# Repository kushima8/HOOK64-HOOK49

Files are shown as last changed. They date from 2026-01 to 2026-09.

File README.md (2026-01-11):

# HOOK64&HOOK49
Keyboard that hooks up to LCD tablets

G8mPXopa0AAUuzB

## HOOK64 Build Guide

[はんだ付け済み版 ビルドガイド（日本語）](HOOK64/Documents//buildguide_pre-soldered.md)

## HOOK49 Build Guide

[はんだ付け済み版 ビルドガイド（日本語）](HOOK49/Documents//buildguide_pre-soldered.md)
  
120px-Cc-by-nc-sa_icon svg

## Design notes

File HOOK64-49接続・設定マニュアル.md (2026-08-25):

# HOOK64/49 接続・設定マニュアル

ビルドガイドに、注意事項などを記載しております。  
本書をお読みになる前に、必ずそちらをご確認ください。  
なお、本書は HOOK49 の画像・画面をもとに説明しておりますが、HOOK64 も操作手順は同じですので、読み替えてご覧ください。　　

## 1. ブックエンドの取り付け（液タブに設置する場合）

本製品を液晶タブレット（液タブ）の上辺に設置する場合は、**本体背面にブックエンドを取り付けて**ご使用ください。  

**手順**

1. 液タブ上辺の形状に合わせて、ブックエンドを適切な角度に折り曲げます。  
2. マスキングテープなどでブックエンドを本体背面に**仮止め**し、液タブに設置して位置や角度を確認します。  
3. 問題がなければ本体を一度取り外し、仮止めのテープをはがしたうえで、**ダクトテープやガムテープ等でブックエンドを本体背面にしっかりと固定**してください。  
   - ※固定時は、可能な限りネジ部分を避けてください。  

> **参考動画**  
> 先代機「HOOK69」の紹介動画内に、ブックエンドの取り付けを実演しているパートがあります。
> 折り曲げ方や固定位置のイメージがつかみやすいので、あわせてご覧ください。  
> https://youtu.be/qUh0zuOqxo4?t=560 （9分20秒ごろ〜）  
>
> ※HOOK64/49 とは筐体サイズが異なりますが、取り付けの考え方は同じです。  

## 2. 接続方法

HOOK64/49は、PCやiPadなどの機器とUSB接続して使用します。  
本体側の端子は USB Type-C もしくは USB Micro‐B です。  

### ■ 使用するケーブル

- Type-C/Micro‐B ⇄ Type-A
- Type-C/Micro‐B ⇄ Type-C  
  ※必ず「データ通信対応ケーブル」をご使用ください。充電専用ケーブルでは動作しません。  

USB端子は精密部品です。  
ケーブルを横方向に強く引っ張ると破損の原因になります。  
必ずまっすぐ抜き差ししてください。  

## 3. 内部のマイコンについて

HOOK64/49の内部には、ピンク色もしくは青色の小さな基板が入っています。  
これがマイコンです。  
このマイコンがHOOK64/49全体の動作を制御しPCとの接続口となっており、取り外すことができます。  

内部のマイコン

※画像はオプションの液晶付きモデルです。液晶がない場合、マイコンはカバーで覆われています。  

これは、

- 故障時に交換しやすくするため
- USB端子に強い力がかかった際に、本体基板へのダメージを減らすため

の設計です。  

そのため、衝撃などで外れることがありますが、**故障ではありません。**  

カバーにより外れにくい構造になっていますが、万が一外れてしまった場合はご連絡ください。  

## 4. Remapとは？

Remapは、ブラウザ上でキーボードの設定を変更できるWebアプリです。  
ソフトのインストールは不要で、Chromeブラウザのみで使用できます。  

Remapでは以下の設定が可能です。  

- キー配置変更
- レイヤー設定
- ダイヤル操作設定

## 5. Remapの使い方

### ① サイトを開く

https://remap-keys.app/  

「Start Remap for your keyboard」をクリックします。  

### ② キーボードを選択

「+KEYBOARD」をクリックします。  

表示された一覧から **HOOK64/49** を選択してください。  

キーボードの選択

接続が成功すると、キーボードのレイアウト画面が表示されます。  

レイアウト画面

## 6. キーの動作確認

右上メニューから **テストマトリクスモード** を選択してください。  

テストマトリクスモードの選択

キーを押すと水色に変わります。  

すべてのキーが反応するか確認してください。  

マトリクステスト

※ダイヤルの回転部分は、このテストモードでは反応表示されません。正常な仕様です。  
ダイヤルの回転部分については、テキストエディターなどを使用して、割り当てた入力が実際に行われるか確認してください。  

各部の名称

## 7. キー配置、ダイヤル操作の変更方法

Remap画面で以下の設定が変更できます。  

- キーの役割
- ダイヤルの回転動作と押し込み

### ■ 基本は「ドラッグ＆ドロップ」で変更します

Remapでは、画面下部のキー一覧からドラッグ＆ドロップする方法が最も簡単です。  

**手順**

1. 画面下部に表示されているキー一覧から、設定したいキーを探します。  
2. マウスでそのキーをクリックしたまま、割り当てたいキーの位置までドラッグします。  
3. ドロップ（マウスを離す）すると設定が変更されます。  

直感的に操作できるため、基本的にはこの方法をおすすめします。  

### ■ キーをクリックして変更する方法

ドラッグ操作が難しい場合は、キーをクリックして直接変更することも可能です。  

1. 変更したいキーをクリックします。  
2. 表示されるキー一覧から割り当てたい機能を選択します。  

### ■ 設定を保存する（重要）

キーの設定を変更しただけでは、本体には保存されていません。  
必ず、右上の **「書き込み」ボタン** を押してください。  

設定変更後、右上の **書き込み** を押すと HOOK64/49に保存されます。  
保存しないと変更内容は反映されません。  

### ■ ダイヤル（回転）の設定方法

ダイヤル部分

ダイヤル部分には、  

- 左回転
- 右回転
- 押し込み

それぞれに別の機能を設定できます。  

ダイヤルの各動作をクリックし、機能を設定してください。  

設定後は必ず **書き込みボタン** を押してください。  

### ■ 文字キーを割り当てる場合

例：Aキーを割り当てたい場合  

- 対象キーをクリック
- 「Basic」カテゴリーから「A」を選択
- 設定後に **書き込み** を押す

### ■ ショートカット（同時押し）を割り当てる場合

例：Ctrl + Z を1キーで実行する場合  

1. 変更したいキーをクリック  

修飾キーの選択

2. Modifier（修飾キー）を選択  
3. Ctrlを選択  
4. Zキーを選択  

Ctrl + Z の設定  

5. 右上の **書き込み** を押す  

これで1キーで「Ctrl + Z」が実行されます。  

### ■ レイヤー機能について

HOOK64/49には **4つのレイヤー（0th〜3rd）** があります。  
レイヤーとは、キー配置を切り替える機能です。  

例：

- 0thレイヤー → 通常操作
- 1stレイヤー → ショートカット
- 2ndレイヤー → ブラシ操作
- 3rdレイヤー → アプリ専用

初期状態では、0thレイヤーがデフォルトのレイヤーになっています。  

現在どのレイヤーが有効かを確認したい場合は、Remapで同じ位置のキーに 0th〜3rdそれぞれ異なる文字を割り当ててください。  
そのキーを押したときに入力される文字で、現在のレイヤーを判別できます。  

### ■ レイヤー切替キーの設定

Remapで以下を割り当てます（Nはレイヤー番号）。

- **MO(N)** … 押している間だけNレイヤーになります
- **TG(N)** … 一度押すとNレイヤーに切り替わり、もう一度押すと元のレイヤーに戻ります
- **TO(N)** … 押すとNレイヤーに切り替わります
  もう一度押しても戻らないため、別のレイヤーに移る場合は他の `TO(N)` を押してください  

レイヤー設定後も、必ず **書き込み** を押してください。  

レイヤー切替キーは上記以外にもあります。  
詳しくはRemapおよびQMKの公式ドキュメントをご参照ください。

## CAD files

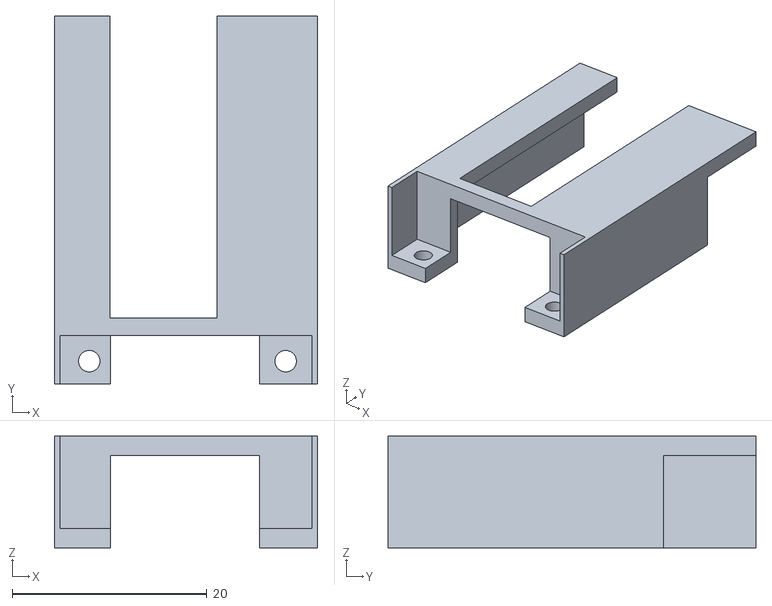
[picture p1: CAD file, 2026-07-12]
HOOK49/STL/hook49・64_cover_oled.stl
27.1 x 37.8 x 11.5

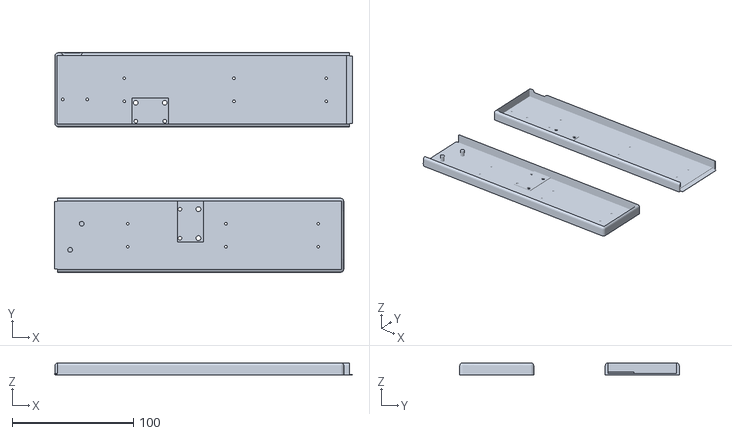
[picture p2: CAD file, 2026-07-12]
HOOK64/STL/hook64_case_V3.stl
245.8 x 181.1 x 10.3

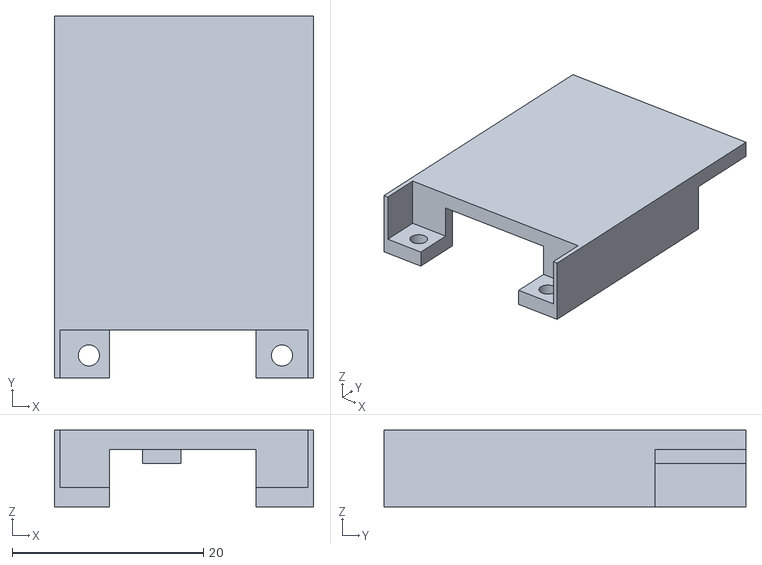
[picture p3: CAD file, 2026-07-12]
HOOK49/STL/hook49・64_cover_2.5.stl
27.1 x 37.8 x 8.00

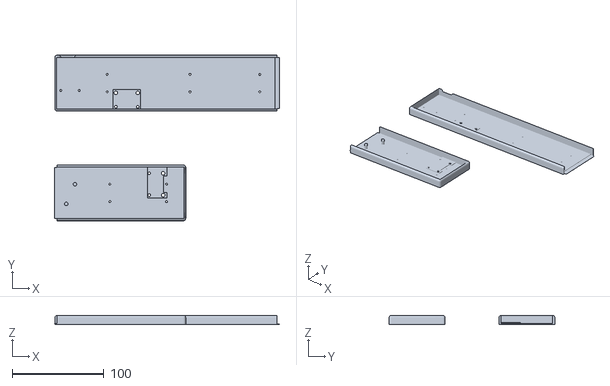
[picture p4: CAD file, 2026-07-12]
HOOK49/STL/hook49_case_V3.stl
245.8 x 181.1 x 10.3

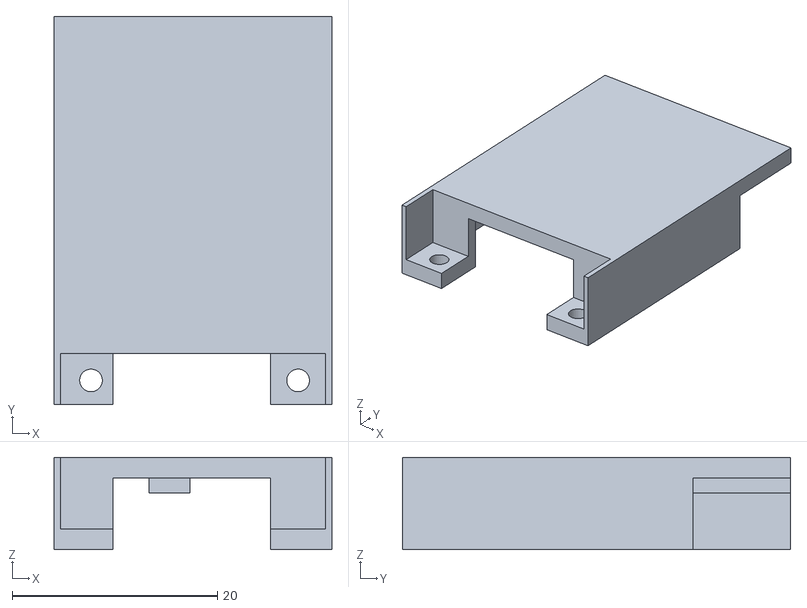
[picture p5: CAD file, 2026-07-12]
HOOK64/STL/hook49・64_cover_3.5.stl
27.1 x 37.8 x 9.00

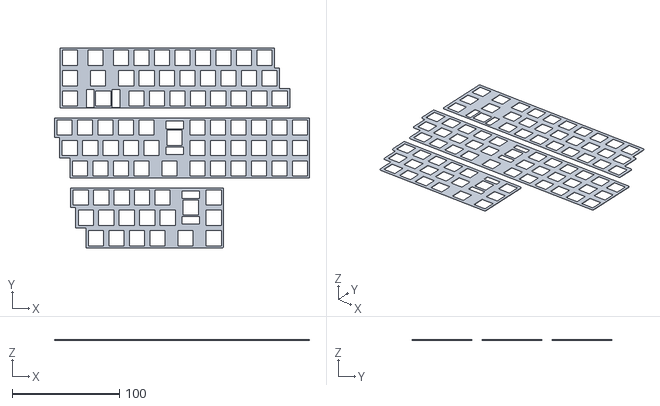
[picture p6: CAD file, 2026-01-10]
HOOK49/STL/hook49・64_plate.stl
237.5 x 186.0 x 1.20

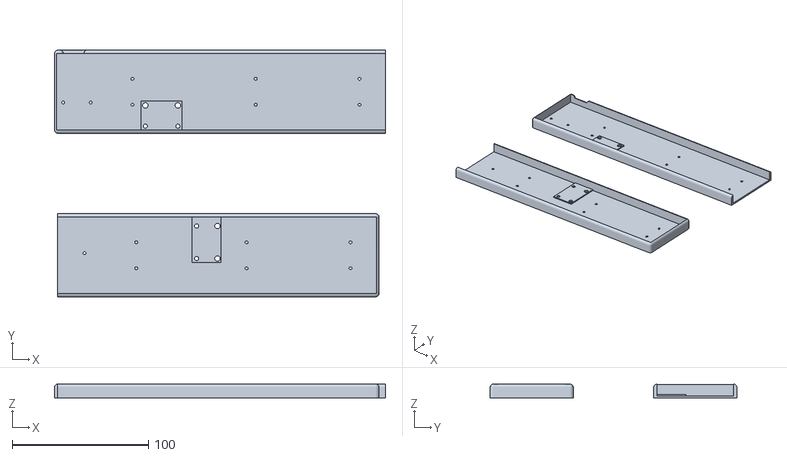
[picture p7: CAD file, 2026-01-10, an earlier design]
HOOK64/STL/hook64_case.stl
242.9 x 181.1 x 10.3

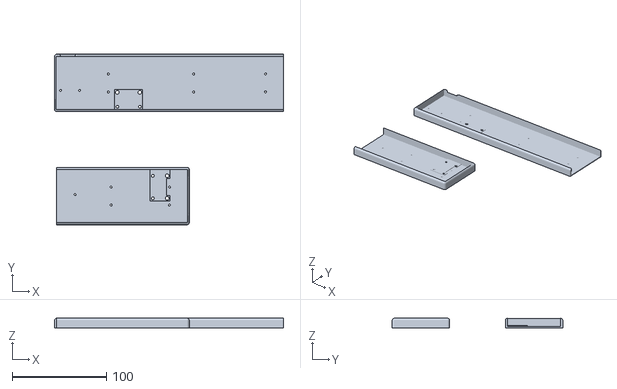
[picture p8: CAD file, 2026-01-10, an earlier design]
HOOK49/STL/hook49_case.stl
242.9 x 181.1 x 10.3

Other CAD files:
HOOK49/STL/hook49_case_V2.stl
HOOK64/STL/hook64_case_V2.stl

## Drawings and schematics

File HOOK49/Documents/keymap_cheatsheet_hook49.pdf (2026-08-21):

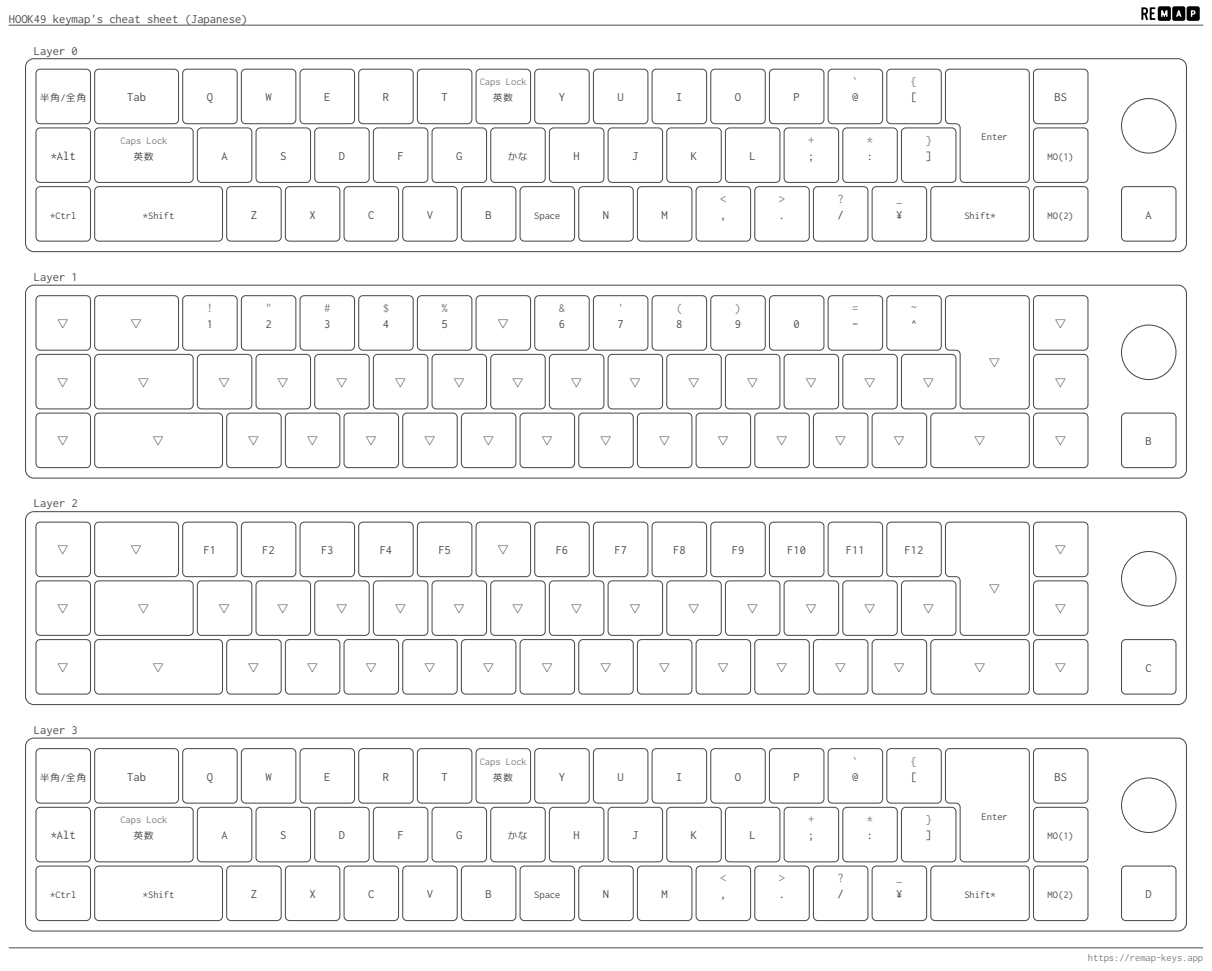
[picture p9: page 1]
Layer 0; Tab; Caps Lock; Enter; *Alt; *Ctrl; *Shift; Space; Shift*; Layer 1; Layer 2; Layer 3

HOOK49 keymap's cheat sheet (Japanese)

https://remap-keys.app

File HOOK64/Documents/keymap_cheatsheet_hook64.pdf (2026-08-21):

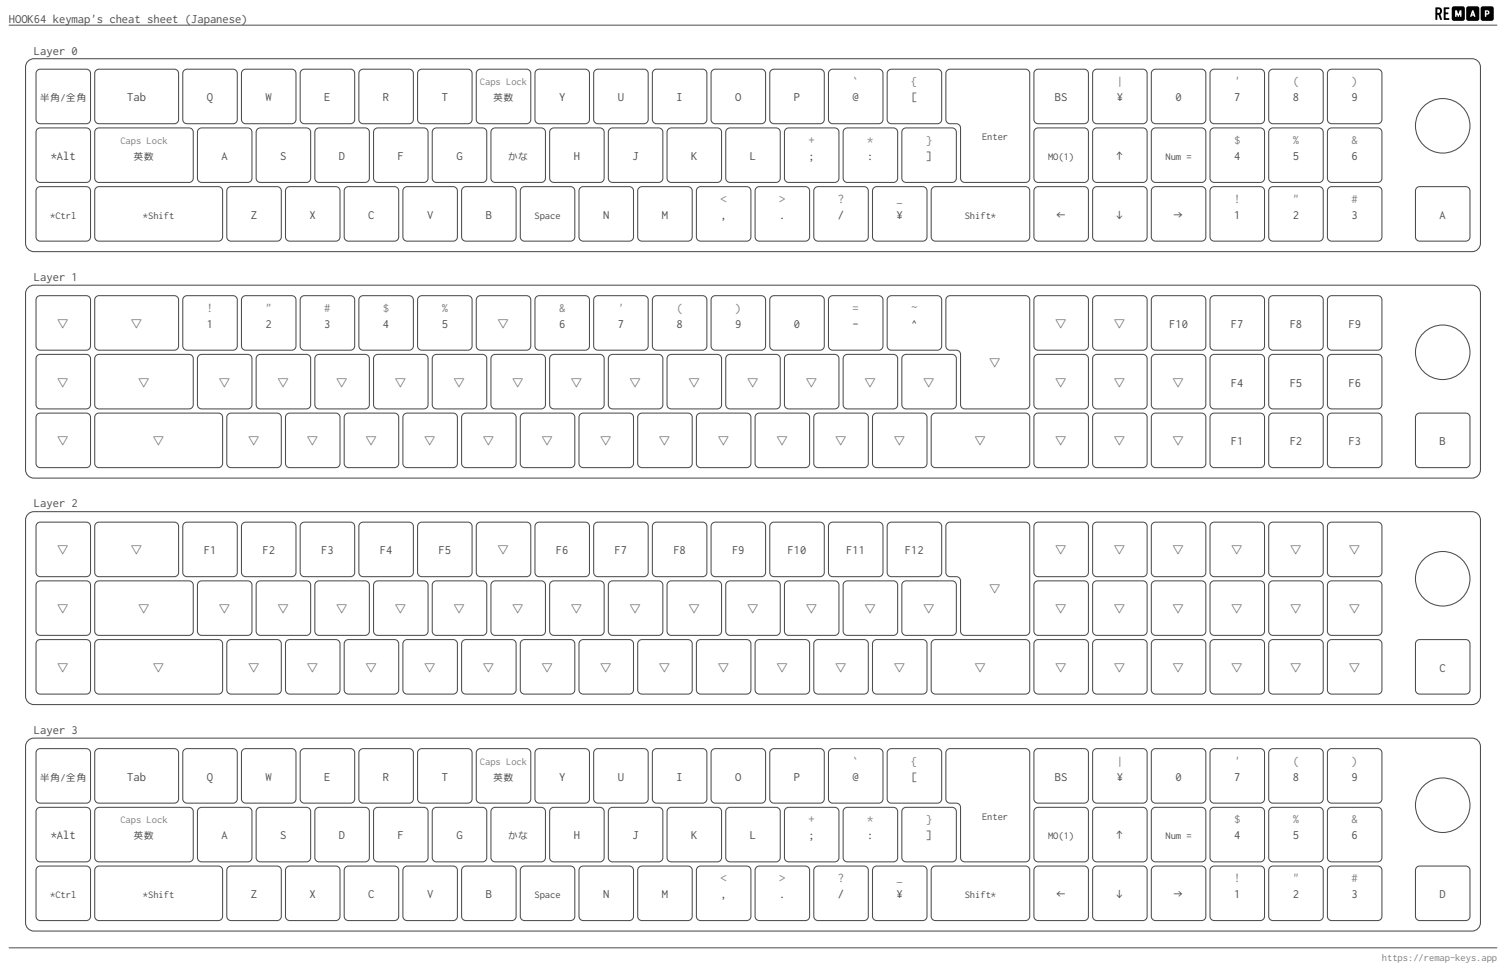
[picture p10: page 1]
Layer 0; Tab; Caps Lock; Enter; *Alt; Num =; *Ctrl; *Shift; Space; Shift*; Layer 1; Layer 2; Layer 3

HOOK64 keymap's cheat sheet (Japanese)

https://remap-keys.app

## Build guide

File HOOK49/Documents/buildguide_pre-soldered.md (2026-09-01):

# HOOK49 はんだ付け済み版 ビルドガイド

## ご購入前にお読みください

本製品をご購入いただいた時点で、下記「譲渡・再販について」の内容にご同意いただいたものとみなします。

### 譲渡・再販について

BOOTHや遊舎工房など、作者本人が販売または委託している場所以外で購入された場合、同梱品の不足や不良品への対応など、各種サポートをいたしかねます。  
そのため、以下のとおりお願いしております。

1. 本製品（完成品・未完成品・付属部品を問わず）を、ネットオークション、フリマサービス、その他の方法により第三者へ有償で譲渡することを禁止します。
2. 本項に反する行為を確認した場合、以後の販売をお断りする場合があります。

## はじめに
G8mPXopa0AAUuzB
このたびはご購入いただきありがとうございます。  
本製品は組み立てが必要なキットです。  
頒布によっては本体が程度組み立て済みの場合がございます。  
その場合は組み立ての「3.トッププレートにキースイッチを取り付け」からお願い致します  
  
作成にあたり不明点や疑問点などがありましたら、作者の[Twitterアカウント](https://twitter.com/kushima8)までリプライやDMでご連絡ください。  
Twitter以外で連絡を頂いても対応が厳しいです。  
FF外からのリプライは通知オフにしており気づかない場合がこざいますご了承ください。  
それとDiscordのコミュニティなどで作者以外の方だけに不明点や疑問点などを質問することは非推奨です。  

HOOK49は液晶タブレットに設置して使用することに主眼開発したキーボードです。  

写真は作成見本であり商品内容と同一ではありません。  
また仕様は予告なく変更されることがあります。  

完成品、未完成品にかかわらずヤフオク!やメルカリなどのネットオークションやフリマなどでの販売、転売は禁止しております。  
Boothや遊舎工房など作者本人が販売または委託している箇所以外で購入された場合、同梱品の不足や不良品の対応などの各種サポートが厳しいためです。  
もし発見した場合は対応します。  
ご理解のほどよろしくお願いいたします。  

ファームウェアに[qmk_firmware](https://github.com/qmk/qmk_firmware)を採用しています。  
QMKにHOOK49のコードはマージされていませんのでこの[ブランチ](https://github.com/kushima8/qmk_firmware/tree/hook)を使用してください。  
動作確認の為のコンパイル済みファームウェアを[HEXファイル](https://github.com/kushima8/HOOK64-HOOK49/tree/main/HOOK49/HEX)と[UF2ファイル](https://github.com/kushima8/HOOK64-HOOK49/tree/main/HOOK49/UF2)を用意しています。  

購入時にpro Microが付属している場合のみあらかじめファームウェアを書き込んであります。  
他のファームウェアを書き込む場合など下記サイトを参考にしてください。  
[（初心者編）自作キーボードにファームウェアを書き込む](https://salicylic-acid3.hatenablog.com/entry/qmk-toolbox)  

GUIから簡単にキー割り当てを変更できる[VIA](https://caniusevia.com/)と[Remap](https://remap-keys.app/)に対応しております。  
ロータリーエンコーダの回転割り当ても含め、設定できますのでご活用ください。  
VIAとRemapについては下記のサイトを参考にしてください。  
[（初心者編）VIAを使ってキーマップを書き換えよう](https://salicylic-acid3.hatenablog.com/entry/via-manual)  
[（初心者編）Remapを使ってキーマップを書き換えよう](https://salicylic-acid3.hatenablog.com/entry/remap-manual)  

以下の部品リストを参考に欠品がないか確認をお願いします。  
欠品や不良品などがありましたら確認したのちに対応いたします。  
ただし、海外など発送が難しい場合はこちらの指定する方法での一部返金などで対応します。  
あらかじめご了承ください。  

## 部品

### キットに付属しているもの

|名称|数量|備考|
|----|:---:|----|
|PCB|1枚||
|トッププレート|2枚||
|ケース|2個||
|M2 6mmスペーサー(ARB-2006E)|13個|丸型両メネジ|
|M2 4mmネジ|26本|
|2Uスタビライザー(Cherry MX互換)|2個|
|ロータリーエンコーダ|1個|Dシャフト|
|ミニブックエンド|2個|

※組み立て済みの場合は「ミニブックエンド」を除く部品が一体となって本体扱いで付属しております。

### 別途、購入が必ず必要なもの
以下の部品は別途購入してください。

|名称|数量|備考|
|----|:---:|----|
|キースイッチ(Kailh Choc V2系統)|49個||
|キーキャップ(Kailh Choc V2系統)|49個|キットに付属しない場合|
|ロータリーエンコーダ用ノブ|1個|Dシャフト キットに付属しない場合|

※使用可能なキースイッチについては、Kailh Choc V2系統のキースイッチ(2PIN)のみとなります。  
　下記動画内で紹介されているキースイッチであれば使用可能ですのでご参考してください。  
　https://www.youtube.com/watch?v=yv6PdiGenEw  

### オプション
以下の部品はオプション品です。
キーボードを光らせたいなどの場合のみ別途購入しはんだ付けを実施してください。

|名称|数量|備考|
|----|:---:|----|
|OLEDモジュール|1個|
|OLED用ピンソケット|1個|
|KB2040|1個||
|コンスルーピンヘッダ(3.5mm 12PIN)|2個|

※動作確認しているPro MicroとKB2040(RP2040 Kee Boar Driver Adafruit)は以下の通りになります。  
　下記以外のPro Microを使用する場合は動作しないことがあります。  
　使用する場合はご自身で調整してください。  
　Pro Micro（単体）黒基盤/青基盤  
　https://shop.yushakobo.jp/products/pro-micro?variant=42225070768359  
　RP2040 Kee Boar Driver  
　https://akizukidenshi.com/catalog/g/g117312/

## 組み立て 
※画像に制作手順が非常に似ているHOOK64の画像を使用しております。
* 1.ケース組み立て
  * 2つあるケースそれぞれにスタビライザーを取り付けてください。  
  * 取り付け後、両方のケースにM2 6mmスペーサーをネジ穴の位置に合わせて配置し、M2 4mmネジで固定してください。  


* 2.PCB取り付け
  * ２つある組み立てたケースに対し、スタビライザーの位置がPCBのネジ穴に合うようにPCBを配置してください。  
  * その後、M2 4mmネジで固定してください。  


* 3.トッププレートにキースイッチを取り付け
  * 2つあるトッププレートそれぞれの穴にキースイッチを取り付けてください。  
  * キースイッチがはまりにくい場合は、ヤスリなどを使用してトッププレートの穴を調整してください。  
  * キースイッチ取り付け後、各キースイッチにキーキャップを取り付けてください。  


* 4.本体にトッププレートとキースイッチを取り付け
  * キースイッチを取り付けたトッププレートを、本体に差し込んでください。  
  * この際、スイッチのピンが曲がらないよう十分ご注意ください。  
  * 取り付け後、[Remap](https://remap-keys.app/)などを使用して、すべてのキースイッチが正しく認識されているか入力確認を行ってください。 

* 5.ブックエンドの取り付け（※画像は制作手順が類似している[HOOK69](https://github.com/kushima8/HOOK69)のものを使用しています）
  * 液晶タブレット上面に設置するため、ブックエンドを本体背面に取り付けます。  
  * 付属のブックエンドを、設置予定の液タブ上面の形状に合わせて折り曲げてください。  




  * マスキングテープなどでキーボード本体に仮止めし、液タブ上面に設置してください。  



  * 設置後、ブックエンドの位置に問題がなければ仮止めを外し、両面テープなどで固定してください。  
  * 固定の際は、ネジ部分を避けるようご注意ください。  

組み立ての手順は、以上です。  

## 接続・設定について

組み立て後の接続方法やキー割り当ての設定については、下記をご覧ください。

[接続・設定マニュアル（日本語）](../../HOOK64-49接続・設定マニュアル.md)

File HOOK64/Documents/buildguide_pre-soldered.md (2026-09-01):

# HOOK64 はんだ付け済み版 ビルドガイド

## ご購入前にお読みください

本製品をご購入いただいた時点で、下記「譲渡・再販について」の内容にご同意いただいたものとみなします。

### 譲渡・再販について

BOOTHや遊舎工房など、作者本人が販売または委託している場所以外で購入された場合、同梱品の不足や不良品への対応など、各種サポートをいたしかねます。  
そのため、以下のとおりお願いしております。

1. 本製品（完成品・未完成品・付属部品を問わず）を、ネットオークション、フリマサービス、その他の方法により第三者へ有償で譲渡することを禁止します。
2. 本項に反する行為を確認した場合、以後の販売をお断りする場合があります。

## はじめに
G8mPXopa0AAUuzB
このたびはご購入いただきありがとうございます。  
本製品は組み立てが必要なキットです。  
頒布によっては本体が程度組み立て済みの場合がございます。  
その場合は組み立ての「3.トッププレートにキースイッチを取り付け」からお願い致します  
  
作成にあたり不明点や疑問点などがありましたら、作者の[Twitterアカウント](https://twitter.com/kushima8)までリプライやDMでご連絡ください。  
Twitter以外で連絡を頂いても対応が厳しいです。  
FF外からのリプライは通知オフにしており気づかない場合がこざいますご了承ください。  
それとDiscordのコミュニティなどで作者以外の方だけに不明点や疑問点などを質問することは非推奨です。  

HOOK64は液晶タブレットに設置して使用することに主眼開発したキーボードです。  

写真は作成見本であり商品内容と同一ではありません。  
また仕様は予告なく変更されることがあります。  

ファームウェアに[qmk_firmware](https://github.com/qmk/qmk_firmware)を採用しています。  
QMKにHOOK64のコードはマージされていませんのでこの[ブランチ](https://github.com/kushima8/qmk_firmware/tree/hook)を使用してください。  
動作確認の為のコンパイル済みファームウェアを[HEXファイル](https://github.com/kushima8/HOOK64-HOOK49/tree/main/HOOK64/HEX)と[UF2ファイル](https://github.com/kushima8/HOOK64-HOOK49/tree/main/HOOK64/UF2)を用意しています。  

購入時にpro Microが付属している場合のみあらかじめファームウェアを書き込んであります。  
他のファームウェアを書き込む場合など下記サイトを参考にしてください。  
[（初心者編）自作キーボードにファームウェアを書き込む](https://salicylic-acid3.hatenablog.com/entry/qmk-toolbox)  

GUIから簡単にキー割り当てを変更できる[VIA](https://caniusevia.com/)と[Remap](https://remap-keys.app/)に対応しております。  
ロータリーエンコーダの回転割り当ても含め、設定できますのでご活用ください。  
VIAとRemapについては下記のサイトを参考にしてください。  
[（初心者編）VIAを使ってキーマップを書き換えよう](https://salicylic-acid3.hatenablog.com/entry/via-manual)  
[（初心者編）Remapを使ってキーマップを書き換えよう](https://salicylic-acid3.hatenablog.com/entry/remap-manual)  

以下の部品リストを参考に欠品がないか確認をお願いします。  
欠品や不良品などがありましたら確認したのちに対応いたします。  
ただし、海外など発送が難しい場合はこちらの指定する方法での一部返金などで対応します。  
あらかじめご了承ください。  

## 部品

### キットに付属しているもの

|名称|数量|備考|
|----|:---:|----|
|PCB|1枚||
|トッププレート|2枚||
|ケース|2個||
|M2 6mmスペーサー(ARB-2006E)|13個|丸型両メネジ|
|M2 4mmネジ|26本|
|2Uスタビライザー(Cherry MX互換)|2個|
|ロータリーエンコーダ|1個|Dシャフト|
|ミニブックエンド|2個|

※組み立て済みの場合は「ミニブックエンド」を除く部品が一体となって本体扱いで付属しております。

### 別途、購入が必ず必要なもの
以下の部品は別途購入してください。

|名称|数量|備考|
|----|:---:|----|
|キースイッチ(Kailh Choc V2系統)|49個||
|キーキャップ(Kailh Choc V2系統)|49個|キットに付属しない場合|
|ロータリーエンコーダ用ノブ|1個|Dシャフト キットに付属しない場合|

※使用可能なキースイッチについては、Kailh Choc V2系統のキースイッチ(2PIN)のみとなります。  
　下記動画内で紹介されているキースイッチであれば使用可能ですのでご参考してください。  
　https://www.youtube.com/watch?v=yv6PdiGenEw  

### オプション
以下の部品はオプション品です。
キーボードを光らせたいなどの場合のみ別途購入しはんだ付けを実施してください。

|名称|数量|備考|
|----|:---:|----|
|OLEDモジュール|1個|
|OLED用ピンソケット|1個|
|KB2040|1個||
|コンスルーピンヘッダ(3.5mm 12PIN)|2個|

※動作確認しているPro MicroとKB2040(RP2040 Kee Boar Driver Adafruit)は以下の通りになります。  
　下記以外のPro Microを使用する場合は動作しないことがあります。  
　使用する場合はご自身で調整してください。  
　Pro Micro（単体）黒基盤/青基盤  
　https://shop.yushakobo.jp/products/pro-micro?variant=42225070768359  
　RP2040 Kee Boar Driver  
　https://akizukidenshi.com/catalog/g/g117312/
 
## 組み立て
* 1.ケース組み立て
  * 2つあるケースそれぞれにスタビライザーを取り付けてください。  
  * 取り付け後、両方のケースにM2 6mmスペーサーをネジ穴の位置に合わせて配置し、M2 4mmネジで固定してください。  


* 2.PCB取り付け
  * ２つある組み立てたケースに対し、スタビライザーの位置がPCBのネジ穴に合うようにPCBを配置してください。  
  * その後、M2 4mmネジで固定してください。  


* 3.トッププレートにキースイッチを取り付け
  * 2つあるトッププレートそれぞれの穴にキースイッチを取り付けてください。  
  * キースイッチがはまりにくい場合は、ヤスリなどを使用してトッププレートの穴を調整してください。  
  * キースイッチ取り付け後、各キースイッチにキーキャップを取り付けてください。  


* 4.本体にトッププレートとキースイッチを取り付け
  * キースイッチを取り付けたトッププレートを、本体に差し込んでください。  
  * この際、スイッチのピンが曲がらないよう十分ご注意ください。  
  * 取り付け後、[Remap](https://remap-keys.app/)などを使用して、すべてのキースイッチが正しく認識されているか入力確認を行ってください。 

* 5.ブックエンドの取り付け（※画像は制作手順が類似している[HOOK69](https://github.com/kushima8/HOOK69)のものを使用しています）
  * 液晶タブレット上面に設置するため、ブックエンドを本体背面に取り付けます。  
  * 付属のブックエンドを、設置予定の液タブ上面の形状に合わせて折り曲げてください。  




  * マスキングテープなどでキーボード本体に仮止めし、液タブ上面に設置してください。  



  * 設置後、ブックエンドの位置に問題がなければ仮止めを外し、両面テープなどで固定してください。  
  * 固定の際は、ネジ部分を避けるようご注意ください。  

組み立ての手順は、以上です。

## 接続・設定について

組み立て後の接続方法やキー割り当ての設定については、下記をご覧ください。

[接続・設定マニュアル（日本語）](../../HOOK64-49接続・設定マニュアル.md)

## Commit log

2026-01-10 add HOOK64 HOOK49
    [hook49case.stl, hook49・64_plate.stl, hook64case.stl]
2026-07-12 add stl
    [hook49_case.stl, hook49_case_V2.stl, hook49_case_V3.stl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]
